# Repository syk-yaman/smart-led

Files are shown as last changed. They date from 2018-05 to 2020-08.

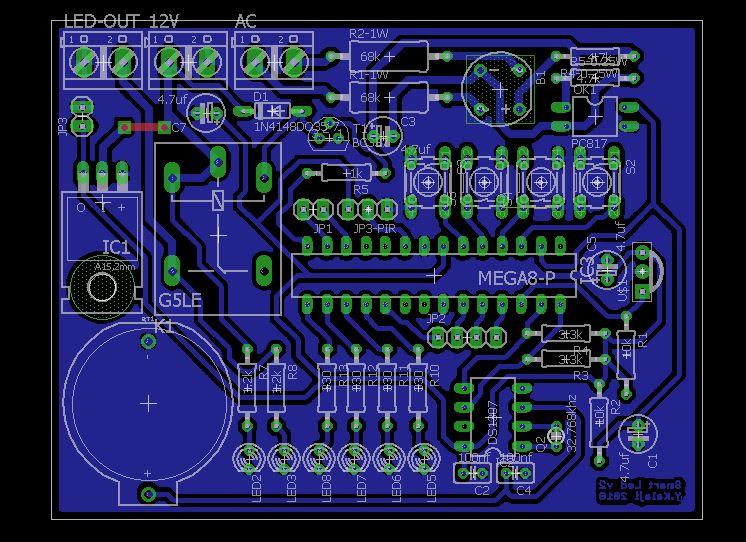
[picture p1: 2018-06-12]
PCB/PCB.JPG

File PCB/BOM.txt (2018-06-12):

Partlist exported from C:/Users/Yaman-PC/projects/smart-led/PCB/SmartLed.sch at 12-Jun-18 10:46 PM

Qty Value        Device           Package          Parts                              Description                          MF MPN          OC_FARNELL OC_NEWARK PROD_ID    SF_SKU   
4                10-XX            B3F-10XX         S2, S3, S4, S5                     OMRON SWITCH                            B3F-1000     176432     36M3542                       
1                79XXL            79XXL            IC1                                VOLTAGE REGULATOR                                                                             
3                AK500/2          AK500/2          12V, AC, LED-OUT                   CONNECTOR                                            unknown    unknown                       
1                BATTERY-20MM_PTH BATTCOM_20MM_PTH BT1                                Battery - Single Cell                                                     BATT-09031 PRT-00783
6                LED3MM           LED3MM           LED2, LED3, LED5, LED6, LED7, LED8 LED                                                                                           
2                PINHD-1X2        1X02             JP1, JP3                           PIN HEADER                                                                                    
1                PINHD-1X3        1X03             JP3-PIR                            PIN HEADER                                                                                    
1                PINHD-1X4        1X04             JP2                                PIN HEADER                                                                                    
1                RB1A             RB1A             B1                                 RECTIFIER                                                                                     
2   1.2k         R-EU_0207/10     0207/10          R7, R8                             RESISTOR, European symbol                                                                     
2   100nf        C-EU025-025X050  C025-025X050     C2, C4                             CAPACITOR, European symbol                                                                    
2   10k          R-EU_0207/10     0207/10          R1, R2                             RESISTOR, European symbol                                                                     
1   1N4148DO35-7 1N4148DO35-7     DO35-7           D1                                 DIODE                                                                                         
1   1k           R-EU_0207/10     0207/10          R5                                 RESISTOR, European symbol                                                                     
2   3.3k         R-EU_0207/10     0207/10          R3, R4                             RESISTOR, European symbol                                                                     
1   32.768khz    CRYSTALTC26V     TC26V            Q2                                 CRYSTAL                                              unknown    unknown                       
4   330          R-EU_0207/10     0207/10          R10, R11, R12, R13                 RESISTOR, European symbol                                                                     
2   4.7k         R-EU_0207/10     0207/10          R4-0.25W, R5-0.25W                 RESISTOR, European symbol                                                                     
4   4.7uf        CPOL-EUE2.5-5    E2,5-5           C1, C3, C5, C7                     POLARIZED CAPACITOR, European symbol                                                          
2   68k          R-EU_0411/15     0411/15          R1-1W, R2-1W                       RESISTOR, European symbol                                                                     
1   BC337        BC337            TO92             T1                                 NPN TRANSISTOR                                                                                
1   DS1307       DS1307           DIL08            IC2                                DS1307                                                                                        
1   G5LE         G5LE             G5LE             K1                                 RELAY                                                unknown    unknown                       
1   MEGA8-P      MEGA8-P          DIL28-3          IC3                                MICROCONTROLLER                                      unknown    unknown                       
1   PC817        PC817            DIL04            OK1                                SHARP OPTO COUPLER                      PC817X4J000F 9707727    97K7059                       
1   PNA460XM     PNA460XM         PNA460XM         U$1                                IR 38KHz receiver

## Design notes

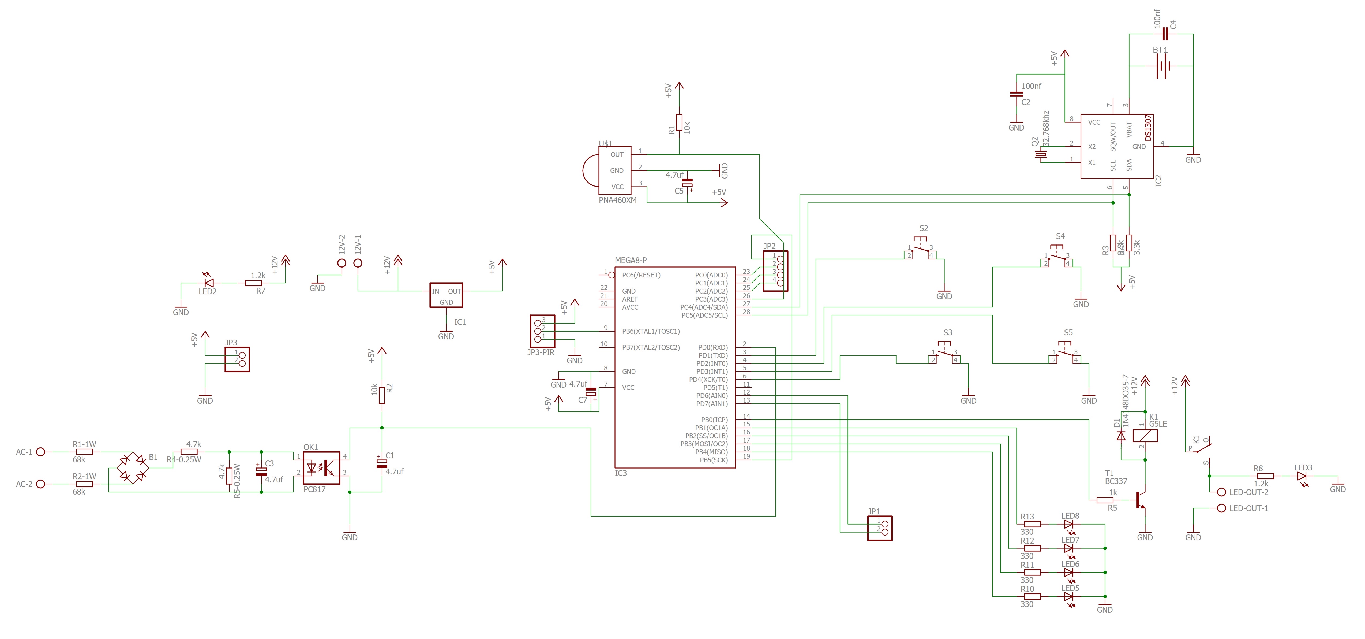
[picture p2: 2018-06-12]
PCB/Schematic.jpg

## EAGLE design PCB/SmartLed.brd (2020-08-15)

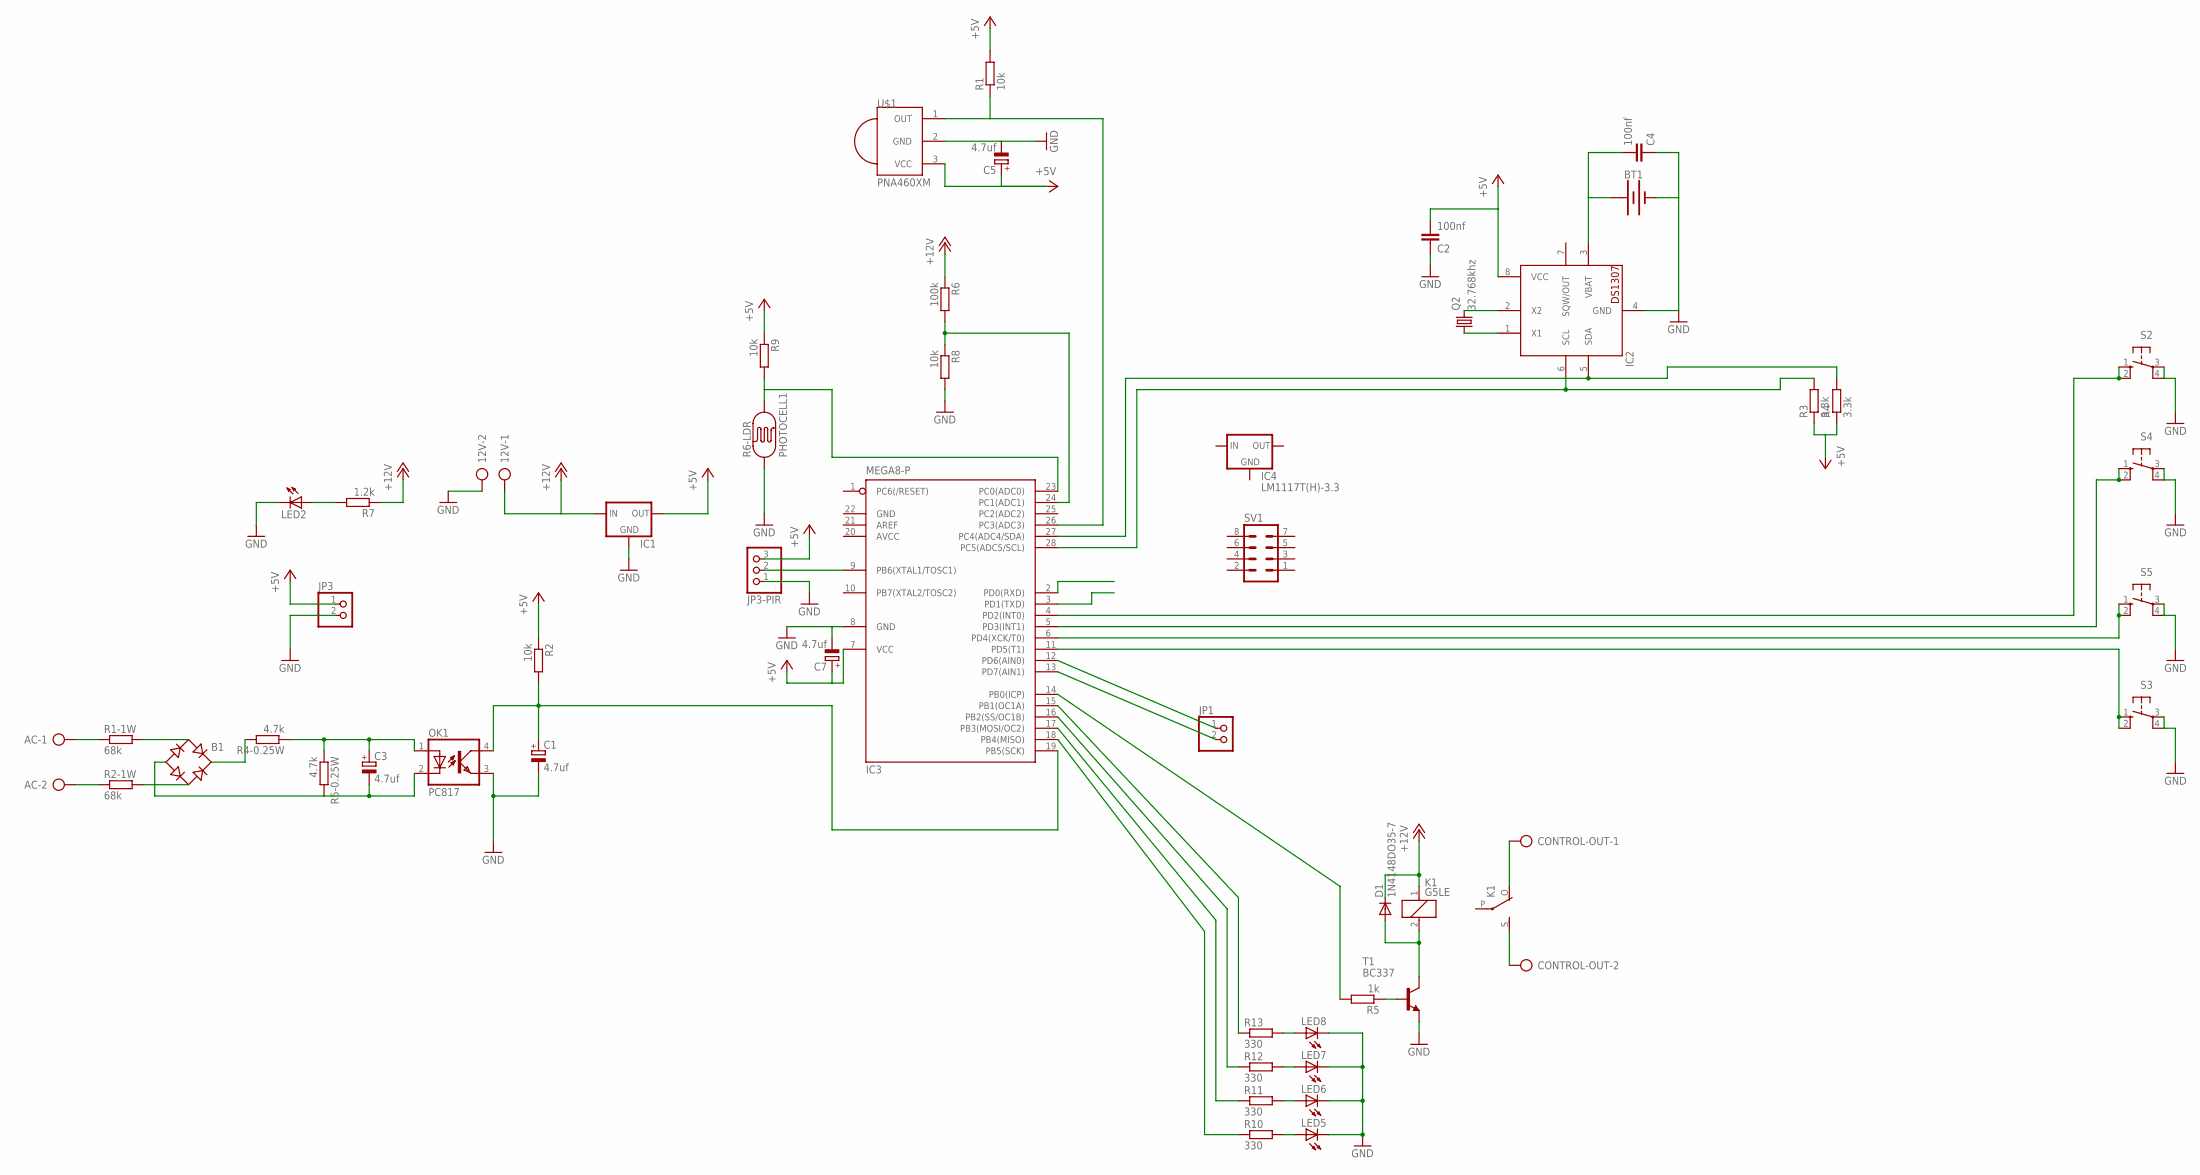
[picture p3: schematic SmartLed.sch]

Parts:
12V: AK500/2
AC: AK500/2
B1: RB1A
BT1: BATTERY-20MM_PTH; BATTCOM_20MM_PTH
C1, C3, C5, C7: 4.7uf; E2,5-5
C2, C4: 100nf; C025-025X050
CONTROL-OUT: AK500/2
D1: 1N4148DO35-7; DO35-7
IC1: 78XXL
IC2: DS1307; DIL08
IC3: MEGA8-P; DIL28-3
IC4: LM1117T(H)-3.3; TO220H
JP1, JP3: PINHD-1X2; 1X02
JP3-PIR: PINHD-1X3; 1X03
K1: G5LE
LED2, LED5, LED6, LED7, LED8: LED3MM
OK1: PC817; DIL04
Q2: 32.768khz; TC26V
R1, R2, R8, R9: 10k; 0207/10
R1-1W, R2-1W: 68k; 0411/15
R3, R4: 3.3k; 0207/10
R4-0.25W, R5-0.25W: 4.7k; 0207/10
R5: 1k; 0207/10
R6: 100k; 0207/10
R6-LDR: PHOTOCELL1; LDR_OFFBOARD
R7: 1.2k; 0207/10
R10, R11, R12, R13: 330; 0207/10
S2, S3, S4, S5: 10-XX; B3F-10XX
SV1: MA04-2
T1: BC337; TO92
U$1: PNA460XM

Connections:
+5V: C2.2, C5.+, C7.+, IC1.OUT, IC2.8 (VCC), IC3.7 (VCC), JP3.1, JP3-PIR.3, R1.2, R2.1, R3.1, R4.1, R9.1, U$1.3 (VCC)
+12V: 12V.1, D1.C, IC1.IN, K1.1, R6.1, R7.1
AVCC: IC3.20 (AVCC)
GND: 12V.2, BT1.2 (-), C1.-, C2.1, C4.1, C5.-, C7.-, IC1.GND, IC2.4 (GND), IC3.8 (GND), IC3.22 (GND), JP3.2, JP3-PIR.1, LED2.K (C), LED5.K (C), LED6.K (C), LED7.K (C), LED8.K (C), OK1.3 (EMIT), R6-LDR.1, R8.2, S2.3, S2.4 (P1), S3.3, S3.4 (P1), S4.3, S4.4 (P1), S5.3, S5.4 (P1), T1.1 (E), U$1.2 (GND)
unnamed: AC.1, R1-1W.1
unnamed: AC.2, R2-1W.1
unnamed: B1.AC1, R1-1W.2
unnamed: B1.AC2, R2-1W.2
unnamed: B1.+, R4-0.25W.2
unnamed: C3.+, OK1.1 (A), R4-0.25W.1, R5-0.25W.1
unnamed: B1.-, C3.-, OK1.2 (C), R5-0.25W.2
unnamed: CONTROL-OUT.2, K1.S
unnamed: R5.1, T1.2 (B)
unnamed: IC3.14 (PB0(ICP)), R5.2
unnamed: C1.+, IC3.19 (PB5(SCK)), OK1.4 (COL), R2.2
unnamed: IC2.6 (SCL), IC3.28 (PC5(ADC5/SCL)), R3.2
unnamed: IC2.5 (SDA), IC3.27 (PC4(ADC4/SDA)), R4.2
unnamed: D1.A, K1.2, T1.3 (C)
unnamed: LED2.A, R7.2
unnamed: CONTROL-OUT.1, K1.O
unnamed: IC3.15 (PB1(OC1A)), R13.1
unnamed: IC3.24 (PC1(ADC1)), R6.2, R8.1
unnamed: IC3.9 (PB6(XTAL1/TOSC1)), JP3-PIR.2
unnamed: IC3.16 (PB2(SS/OC1B)), R12.1
unnamed: IC2.1 (X1), Q2.1
unnamed: IC2.2 (X2), Q2.2
unnamed: LED5.A, R10.2
unnamed: IC3.17 (PB3(MOSI/OC2)), R11.1
unnamed: LED6.A, R11.2
unnamed: IC3.18 (PB4(MISO)), R10.1
unnamed: LED7.A, R12.2
unnamed: IC3.4 (PD2(INT0)), S2.1 (S), S2.2 (S1)
unnamed: LED8.A, R13.2
unnamed: IC3.11 (PD5(T1)), S3.1 (S), S3.2 (S1)
unnamed: IC3.5 (PD3(INT1)), S4.1 (S), S4.2 (S1)
unnamed: IC3.6 (PD4(XCK/T0)), S5.1 (S), S5.2 (S1)
unnamed: IC3.23 (PC0(ADC0)), R6-LDR.2, R9.2
unnamed: IC3.12 (PD6(AIN0)), JP1.1
unnamed: IC3.13 (PD7(AIN1)), JP1.2
unnamed: BT1.1 (+), C4.2, IC2.3 (VBAT)
unnamed: IC3.26 (PC3(ADC3)), R1.1, U$1.1 (OUT)

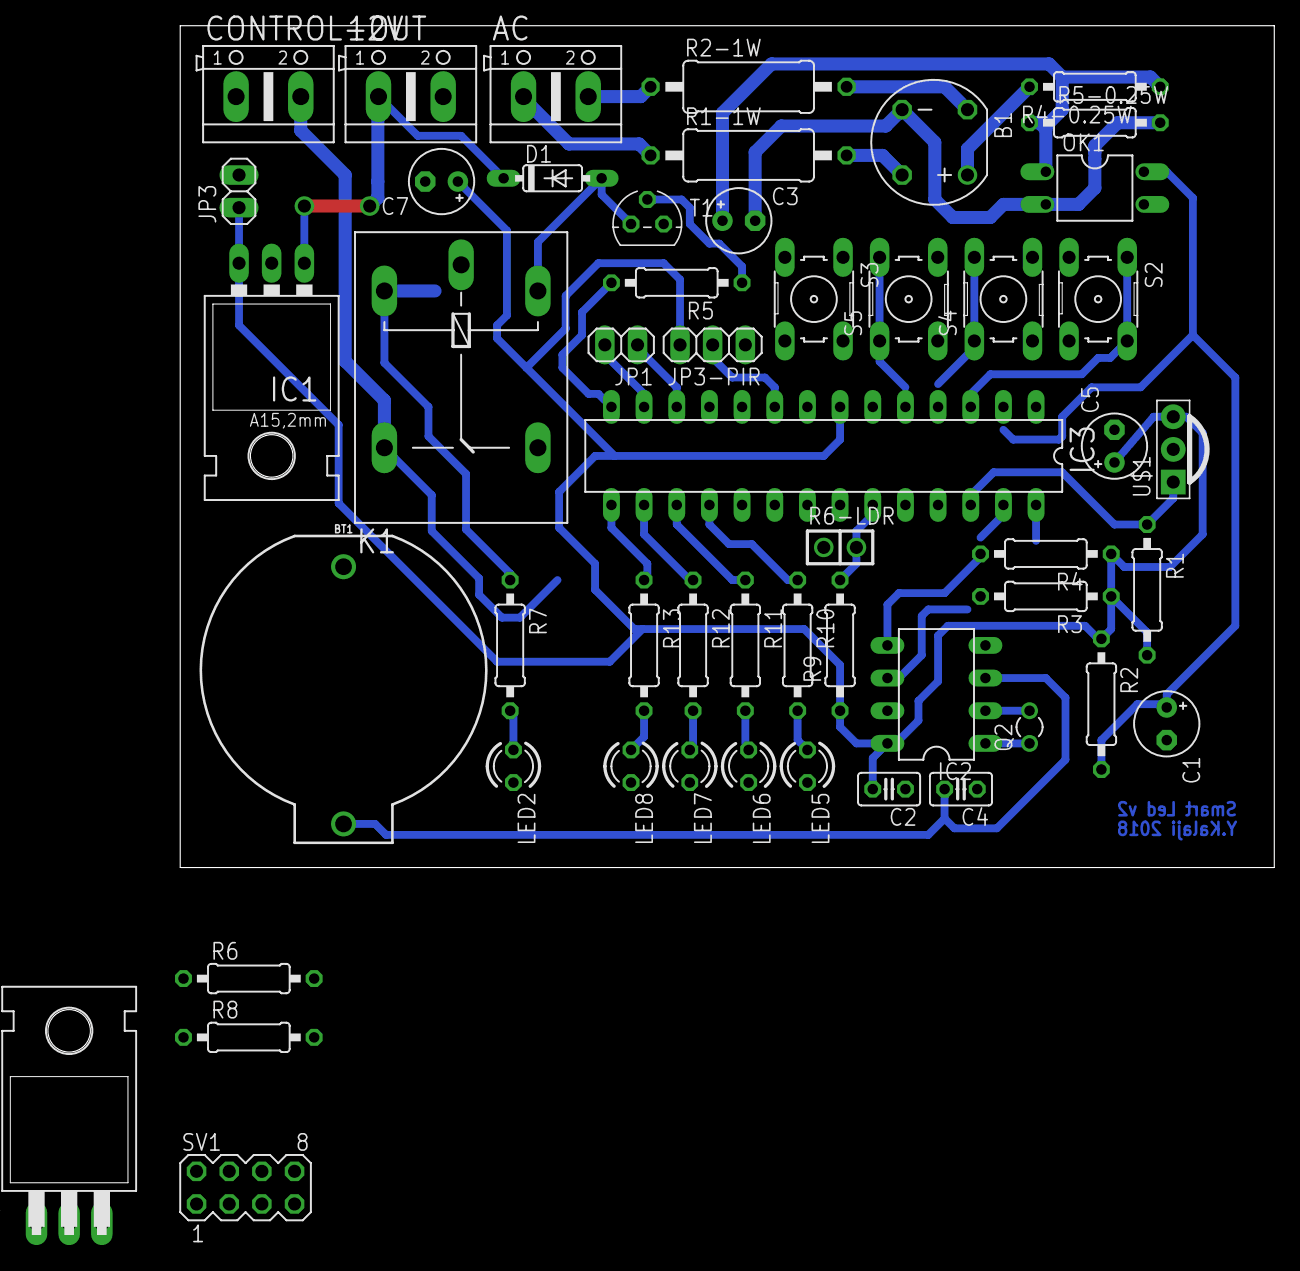
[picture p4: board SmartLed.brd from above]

Board: 2 copper layers, 85.1 x 65.5 mm, 52 parts (0 on the bottom side), 40 nets.

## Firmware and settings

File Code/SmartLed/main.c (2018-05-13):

#include <avr/io.h>
#include "rtc.h"
#include <util/delay.h>
#include <avr/wdt.h>

//Macros
#define bit_is_low(sfr,bit)(!(_SFR_BYTE(sfr) & _BV(bit)))
#define bit_is_high(sfr,bit)(_SFR_BYTE(sfr) & _BV(bit))

//Head of methods
void checkElectricityStatus();
int isActiveTime(rtc_t rtc);
void changeOutputLedStatus(int status);
void changeElectricityInidicator(int status);
void changeTimeInidicator(int status); 
void changeAutoInidicator(int status);
void setRtcTime(rtc_t rtc);
void initPorts();
void checkManualButton();
void checkOnButton();
void checkOffButton();
void blinkAccordingToHourNumber(rtc_t rtc);
void checkShowTimeButton(rtc_t rtc);

//Button status
int manualButtonStatus = 1;
int turnOnButtonStatus = 1;
int turnOffButtonStatus = 1;
int showTimeButtonStatus = 1;
int electricityStatus = 0;

//Variables
int isManualControl = 0;

int main()
{
	OSCCAL=0xFF;
	rtc_t rtc;
	RTC_Init();
	initPorts();
	wdt_enable(WDTO_2S);
	//setRtcTime(rtc);
	
	while(1)
	{
		wdt_reset();
		RTC_GetDateTime(&rtc);
		checkShowTimeButton(rtc);

		checkManualButton();
		checkElectricityStatus();

		if(isManualControl == 1){
			changeAutoInidicator(1);
			} else {
			changeAutoInidicator(0);
		}

		if(isManualControl == 0)
		{
			if(isActiveTime(rtc) == 1)
			{
				changeTimeInidicator(1);
				if(electricityStatus==1)
				{
					changeOutputLedStatus(0);
					changeElectricityInidicator(1);
				}
				else
				{
					changeOutputLedStatus(1);
					changeElectricityInidicator(0);
				}
			}
			else
			{
				changeTimeInidicator(0);
				changeOutputLedStatus(0);
			}
		}
		else
		{
			checkOnButton();
			checkOffButton();
		}

		if(electricityStatus==1)
		{
			changeElectricityInidicator(1);
		}
		else
		{
			changeElectricityInidicator(0);
		}
		
	}
	return (0);
}

void checkManualButton()
{
	if(bit_is_low(PIND,1))  //Manual control button pressed (PIND & 0b00000010)==0
	{
		if(manualButtonStatus == 1)
		{
			manualButtonStatus = 0;

			if(isManualControl == 1)
			{
				isManualControl = 0;
			}
			else
			{
				isManualControl = 1;
			}

		}
	}
	else
	{
		if(manualButtonStatus == 0)
		{
			manualButtonStatus = 1;
		}
	}
}

void checkOnButton()
{
	if(bit_is_low(PIND,2))  //Manual control button pressed (PIND & 0b00000010)==0
	{
		if(turnOnButtonStatus == 1)
		{
			turnOnButtonStatus = 0;
			changeOutputLedStatus(1);
		}
	}
	else
	{
		if(turnOnButtonStatus == 0)
		{
			turnOnButtonStatus = 1;
		}
	}
}

void checkOffButton()
{
	if(bit_is_low(PIND,3))  //Manual control button pressed (PIND & 0b00000010)==0
	{
		if(turnOnButtonStatus == 1)
		{
			turnOnButtonStatus = 0;
			changeOutputLedStatus(0);
		}
	}
	else
	{
		if(turnOnButtonStatus == 0)
		{
			turnOnButtonStatus = 1;
		}
	}
}

void checkShowTimeButton(rtc_t rtc)
{
	if(bit_is_low(PIND,4))  //Manual control button pressed (PIND & 0b00000010)==0
	{
		if(showTimeButtonStatus == 1)
		{
			showTimeButtonStatus = 0;
			blinkAccordingToHourNumber(rtc);
		}
	}
	else
	{
		if(showTimeButtonStatus == 0)
		{
			showTimeButtonStatus = 1;
		}
	}

}

void checkElectricityStatus(){
	if(bit_is_low(PIND,0))  //Manual control button pressed (PIND & 0b00000010)==0
	{
		if(electricityStatus == 0)
		{
			electricityStatus = 1;
		}
	}
	else
	{
		if(electricityStatus == 1)
		{
			electricityStatus = 0;
		}
	}
}

void blinkAccordingToHourNumber(rtc_t rtc)
{

	
	uint8_t hourNum = rtc.hour;
	uint8_t i = 0x00;

	for( i = 0x00 ; i < hourNum ; i = i + 0x01)
	{
		wdt_reset();
		if(i == 0x0A || i == 0x0B || i == 0x0C || i == 0x0D || i == 0x0E || i == 0x0F ||
		i == 0x1A || i == 0x1B || i == 0x1C || i == 0x1D || i == 0x1E || i == 0x1F)
		{
			continue;
		}
		PORTB = PORTB | 0b00010000;
		_delay_ms(30);
		wdt_reset();
		PORTB = PORTB & 0b11101111;
		_delay_ms(40);
	}

	_delay_ms(80);

	uint8_t minNum = rtc.min;
	i = 0x00;

	if(minNum>=0x10)
	{
		minNum = minNum - 0x06 ;
	}
	else if( minNum >= 0x20)
	{
		minNum = minNum - 0x0C ;
	}
	else if( minNum >= 0x20)
	{
		minNum = minNum - 0x12 ;
	}
	else if( minNum >= 0x30)
	{
		minNum = minNum - 0x18 ;
	}
	else if( minNum >= 0x40)
	{
		minNum = minNum - 0x1E ;
	}
	else if( minNum >= 0x50)
	{
		minNum = minNum - 0x24 ;
	}

	for( i = 0x00 ; i < minNum ; i = i + 0x01)
	{
		wdt_reset();
		PORTB = PORTB | 0b00010000;
		_delay_ms(20);
		wdt_reset();
		PORTB = PORTB & 0b11101111;
		_delay_ms(30);
	}

}
int isActiveTime(rtc_t rtc){
	if(rtc.weekDay != 5) //Not Friday
	{
		if(rtc.hour>=0x12)
		{
			if(rtc.hour <= 0x18)
			{
				return 1;
			}
		}
	}
	return 0;
}

void changeOutputLedStatus(int status){
	if(status ==1)
	{
		PORTB = PORTB | 0b00000001;
	}
	else
	{
		PORTB = PORTB & 0b11111110;
	}
}

void changeElectricityInidicator(int status){
	if(status ==1)
	{
		PORTB = PORTB | 0b00000010;
	}
	else
	{
		PORTB = PORTB & 0b11111101;
	}
}

void changeTimeInidicator(int status){
	if(status ==1 )
	{
		PORTB = PORTB | 0b00000100;
	}
	else
	{
		PORTB = PORTB & 0b11111011;
	}
}

void changeAutoInidicator(int status){
	if(status ==1 )
	{
		PORTB = PORTB | 0b00001000;
	}
	else
	{
		PORTB = PORTB & 0b11110111;
	}
}

void setRtcTime(rtc_t rtc){
	rtc.hour = 0x12; //  10:40:20 am
	rtc.min =  0x02;
	rtc.sec =  0x00;

	rtc.date = 0x25; //1st Jan 2016
	rtc.month = 0x04;
	rtc.year = 0x18;
	rtc.weekDay = 3;
	
	// Friday: 5th day of week considering monday as first day.
	/*##### Set the time and Date only once. Once the Time and Date is set, comment these lines
	and reflash the code. Else the time will be set every time the controller is reset*/
	RTC_SetDateTime(&rtc);  //  10:40:20 am, 1st Jan 2016
}

void initPorts(){
	DDRD = 0x00; // Set PORT D to input
	DDRB = 0xFF; // Set PORT B to output

	PORTD = 0b11111110; //enable pull-ups

	//DDRD &= ~(1<<1); // configure PB0 as an input
	//PORTD |= (1<<1); // enable the pull-up on PB0

	//DDRD &= ~(1 << DDD0);     // Clear the PD0 pin
	//DDRD &= ~(1 << DDD1);     // Clear the PD1 pin
	//DDRD &= ~(1 << DDD2);     // Clear the PD2 pin
	//DDRD &= ~(1 << DDD3);
	//DDRD &= ~(1 << DDD4);
	//
	//PORTD |= (1 << PORTD0);    // turn On the Pull-up
	//PORTD |= (1 << PORTD1);    // turn On the Pull-up
	//PORTD |= (1 << PORTD2);    // turn On the Pull-up
	//PORTD |= (1 << PORTD3);	   // turn On the Pull-up
	
}

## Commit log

2018-04-24 Add 100n capacitor beside 3.6v lithium battery & change the battery footprint
    [SmartLed.brd, SmartLed.sch]
2018-04-24 Move library folder inside PCB folder
2018-04-25 Fix a small bug in current active time method
    [main.c]
2018-05-01 Add watchdog timer
2018-06-08 Infrared receiver was added & crystal footprint size was corrected
    [SmartLed.brd, SmartLed.sch]
2018-06-08 Refactor PCB design (several enhancements)
    [SmartLed.brd, SmartLed.sch]
2018-06-09 Add PIR sensor pins to PCB
    [SmartLed.brd, SmartLed.sch]
2018-06-11 Add a pinhead for light sensor
    [SmartLed.brd, SmartLed.sch]
2018-06-12 Add Bill of materials
2018-06-12 Add PCB & Schematic images
2018-06-16 Fix wrong voltage regulator footprint
    [SmartLed.brd, SmartLed.sch]
2018-06-16 Add a LDR off-board sensor
    [SmartLed.brd, SmartLed.sch]
2020-08-15 Working on adding battery voltage meter & adding esp8266 connections header
    [SmartLed.brd, SmartLed.sch]
2020-08-15 Add a library for 3.3v voltage regulator

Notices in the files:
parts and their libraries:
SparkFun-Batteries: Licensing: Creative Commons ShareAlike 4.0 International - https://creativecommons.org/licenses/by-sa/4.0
